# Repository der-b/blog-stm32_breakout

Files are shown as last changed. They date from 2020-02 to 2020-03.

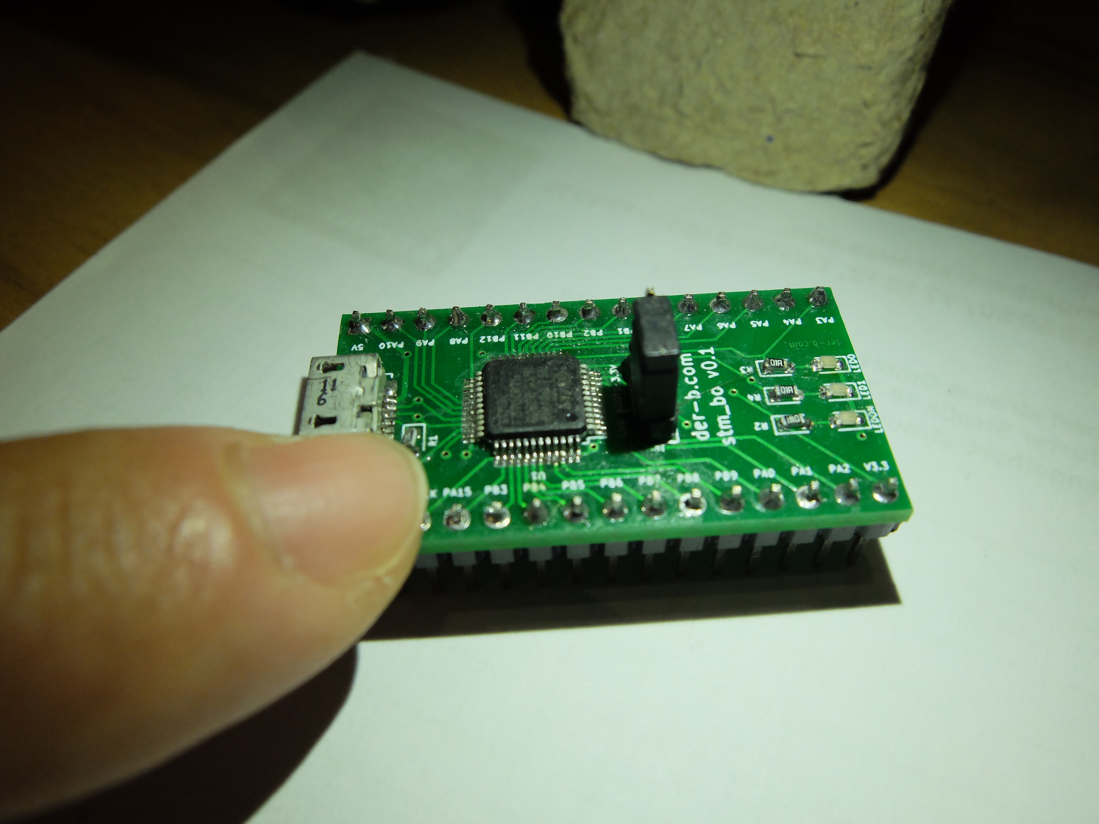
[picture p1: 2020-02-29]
img/DSCF3036.JPG

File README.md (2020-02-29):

# STM32 Breakout

This Project contains all files for my first self designed breakout board with an STM32F070CBT6 microcontroller.

The *schematic* subfolder contains all files related to the board design
The *software* subfolder contains two example firmwares.
In *img* you can find images of the assembled  board.

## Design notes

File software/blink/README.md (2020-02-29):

# Blink

This programm lets the two LEDs on the board blink.

## Compile

``` bash
TARGETS=stm32/f0 make -C libopencm3
make
```

## Download to Board

``` bash
make download
```

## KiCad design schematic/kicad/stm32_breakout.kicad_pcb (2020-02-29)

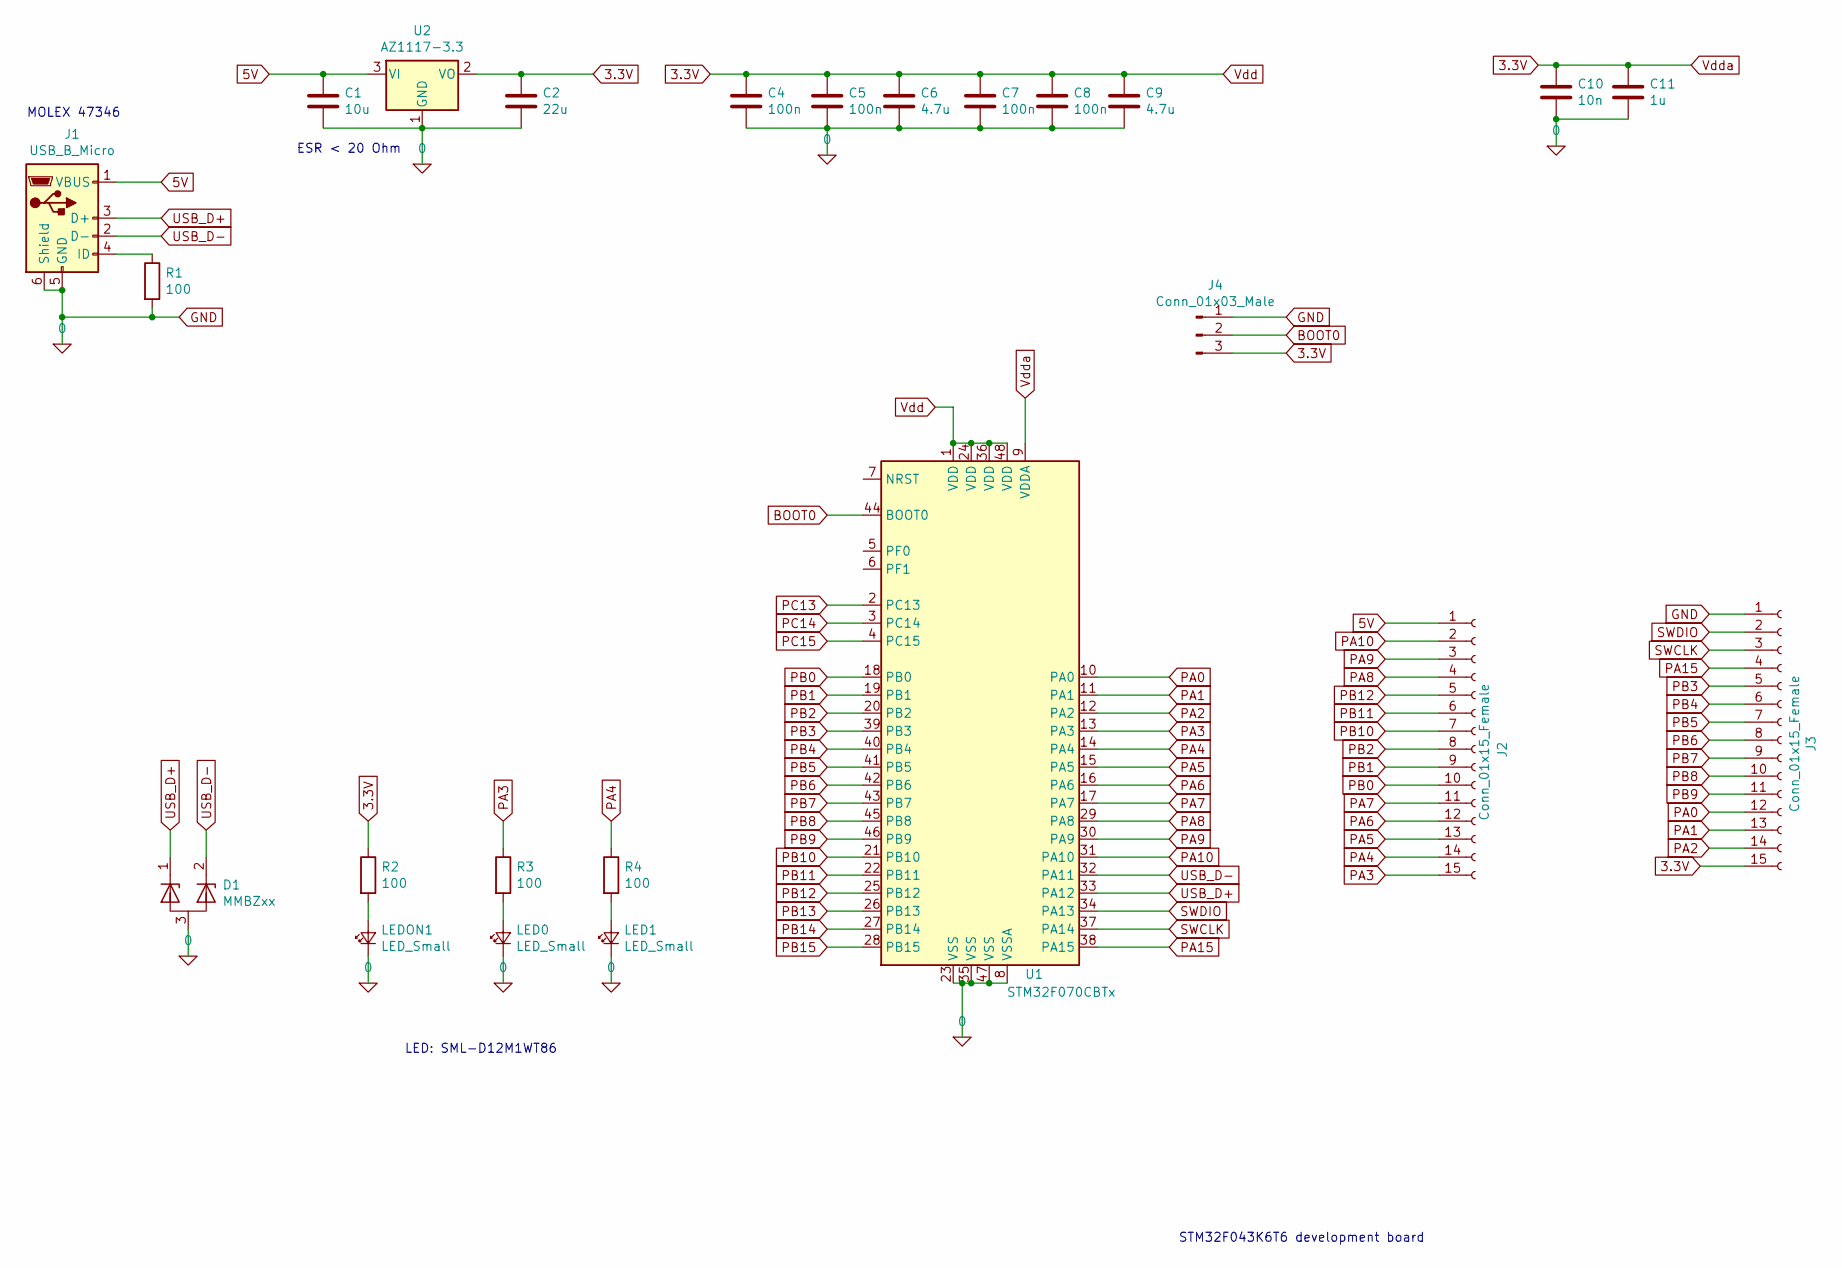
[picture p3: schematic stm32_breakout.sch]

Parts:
C1: 10u; LED_0603_1608Metric
C2: 22u; LED_0603_1608Metric
C4, C5, C7, C8: 100n; LED_0603_1608Metric
C6, C9: 4.7u; LED_0603_1608Metric
C10: 10n; LED_0603_1608Metric
C11: 1u; LED_0603_1608Metric
D1: MMBZxx; SOT-23
J1: USB_B_Micro; USB_Micro-B_Molex_47346-0001
J2, J3: Conn_01x15_Female; PinHeader_1x15_P2.54mm_Vertical
J4: Conn_01x03_Male; PinHeader_1x03_P2.54mm_Vertical
LED0, LED1: LED_Small; LED_0603_1608Metric
LEDON1: LED_Small; LED_0603_1608Metric
R1, R2, R3, R4: 100; LED_0603_1608Metric
U1: STM32F070CBTx; LQFP-48_7x7mm_P0.5mm
U2: AZ1117-3.3; SOT-223

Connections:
3.3V: C2.1, C4.1, C5.1, C6.1, C7.1, C8.1, C9.1, C10.1, C11.1, J3.15, J4.3, R2.1, U1.1 (VDD), U1.9 (VDDA), U1.24 (VDD), U1.36 (VDD), U1.48 (VDD), U2.2 (VO)
5V: C1.1, J1.1 (VBUS), J2.1, U2.3 (VI)
BOOT0: J4.2, U1.44 (BOOT0)
GND: C1.2, C2.2, C4.2, C5.2, C6.2, C7.2, C8.2, C9.2, C10.2, C11.2, D1.3 (A), J1.5 (GND), J1.6 (Shield), J3.1, J4.1, LED0.1 (K), LED1.1 (K), LEDON1.1 (K), R1.2, U1.8 (VSSA), U1.23 (VSS), U1.35 (VSS), U1.47 (VSS), U2.1 (GND); also elsewhere on the board
unnamed: J1.4 (ID), R1.1
unnamed: LED0.2 (A), R3.2
unnamed: LED1.2 (A), R4.2
unnamed 7: LEDON1.2 (A), R2.2; also elsewhere on the board
PA0: J3.12, U1.10 (PA0)
PA1: J3.13, U1.11 (PA1)
PA2: J3.14, U1.12 (PA2)
PA3: J2.15, R3.1, U1.13 (PA3)
PA4: J2.14, R4.1, U1.14 (PA4)
PA5: J2.13, U1.15 (PA5)
PA6: J2.12, U1.16 (PA6)
PA7: J2.11, U1.17 (PA7)
PA8: J2.4, U1.29 (PA8)
PA9: J2.3, U1.30 (PA9)
PA10: J2.2, U1.31 (PA10)
PA15: J3.4, U1.38 (PA15)
PB0: J2.10, U1.18 (PB0)
PB1: J2.9, U1.19 (PB1)
PB2: J2.8, U1.20 (PB2)
PB3: J3.5, U1.39 (PB3)
PB4: J3.6, U1.40 (PB4)
PB5: J3.7, U1.41 (PB5)
PB6: J3.8, U1.42 (PB6)
PB7: J3.9, U1.43 (PB7)
PB8: J3.10, U1.45 (PB8)
PB9: J3.11, U1.46 (PB9)
PB10: J2.7, U1.21 (PB10)
PB11: J2.6, U1.22 (PB11)
PB12: J2.5, U1.25 (PB12)
PB13: U1.26 (PB13)
PB14: U1.27 (PB14)
PB15: U1.28 (PB15)
PC13: U1.2 (PC13)
PC14: U1.3 (PC14)
PC15: U1.4 (PC15)
SWCLK: J3.3, U1.37 (PA14)
SWDIO: J3.2, U1.34 (PA13)
USB_D+: D1.1 (K), J1.3 (D+), U1.33 (PA12)
USB_D-: D1.2 (K), J1.2 (D-), U1.32 (PA11)

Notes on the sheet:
ESR < 20 Ohm
LED: SML-D12M1WT86
MOLEX 47346
STM32F043K6T6 development board

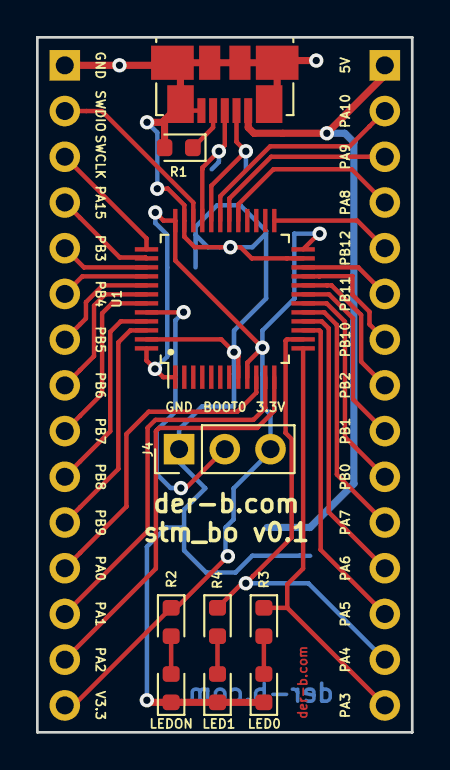
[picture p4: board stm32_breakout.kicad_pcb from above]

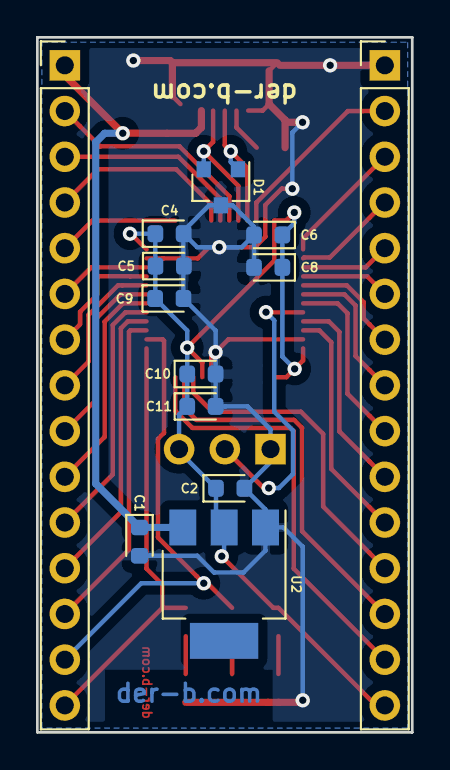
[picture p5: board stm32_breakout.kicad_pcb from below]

Board: 2 copper layers, 20.8 x 38.6 mm, 23 parts (13 on the bottom side), 37 nets.

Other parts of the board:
LEDON: LED_Small; LED_0603_1608Metric

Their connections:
GND: LEDON.1; also elsewhere on the board
unnamed 7: LEDON.2; also elsewhere on the board

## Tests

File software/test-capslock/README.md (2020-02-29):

# Capslock

With this program, the board will register as USB keyboard and listens to the status of caps lock and the numpad status. Depending on the status it will turn on the LEDs.

This is based on [tomu-capslock](https://github.com/der-b/tomu-capslock)

## Compile

``` bash
TARGETS=stm32/f0 make -C libopencm3
make
```

## download to board

``` bash
make download
```

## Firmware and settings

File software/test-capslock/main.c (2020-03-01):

#include <libopencm3/stm32/rcc.h>
#include <libopencm3/stm32/gpio.h>
#include <libopencm3/stm32/exti.h>
#include <libopencm3/stm32/f0/nvic.h>
#include <libopencm3/stm32/timer.h>
#include <libopencm3/usb/usbd.h>
#include <libopencm3/usb/hid.h>

#include <stdbool.h>
#include <stdio.h>
#include <string.h>
#include "HID_Report.h"

#define AHB_FREQUENCY 14000000

#define VENDOR_ID                 0x1209    /* see: http://pid.codes/ */
#define PRODUCT_ID                0x0001    /* test product id: http://pid.codes/1209/0001/ */
#define DEVICE_VER                0x0100    /* Program version */

/* Reference [1]: USB 3.2 Revision 1.0 */
/* Reference [2]: Device Class Definitions for Human Interface Devices (HID) Version 1.11 */
/* Reference [3]: https://eleccelerator.com/tutorial-about-usb-hid-report-descriptors/ */

/* See [1] Table 9-11 */
#define USB_VERSION_2_0 (0x0200)

/* See [1] Table 9-25 "bEndpointAddress" */
#define KEYBOARD_ADDRESS (0x81)

/* Buffer to be used for control requests. */
uint8_t usbd_control_buffer[128];
usbd_device *g_usbd_dev = 0;

/*
 * Example from [2] Section E.6
 */
static const uint8_t hid_report[] = {
USAGE_PAGE (GENERIC_DESKTOP_CONTROLS),
USAGE (KEYBOARD),
COLLECTION (APPLICATION),
	USAGE_PAGE (KEYBOARD_KEYPAD),
	USAGE_MINIMUM (224),
	USAGE_MAXIMUM (231),
	LOGICAL_MINIMUM (0),
	LOGICAL_MAXIMUM (1),
	REPORT_SIZE (1),
	REPORT_COUNT (8),
	INPUT (DATA | VARIABLE | ABSOLUTE),

	REPORT_COUNT (1),
	REPORT_SIZE (8),
	INPUT (CONSTANT),

	REPORT_COUNT (6),
	REPORT_SIZE (8),
	LOGICAL_MINIMUM (0),
	LOGICAL_MAXIMUM (101),
	USAGE_PAGE (KEYBOARD_KEYPAD),
	USAGE_MINIMUM (0),
	USAGE_MAXIMUM (101),
	INPUT (DATA | ARRAY),

	REPORT_COUNT (5),
	REPORT_SIZE (1),
	USAGE_PAGE (LEDS),
	USAGE_MINIMUM (1),
	USAGE_MAXIMUM (7),
	OUTPUT (DATA | VARIABLE | ABSOLUTE),

	REPORT_COUNT (1),
	REPORT_SIZE (3),
	OUTPUT (CONSTANT),

END_COLLECTION, // END_COLLECTION
};


/*
 * See [2] Section 6.2.1
 */
struct tomu_hid_report {
	struct usb_hid_descriptor hid_d;
	uint8_t bDescriptorType;
	uint16_t wDescriptorLenght;
} __attribute__((packed));

/*
 * Device descriptor
 * See [1] Table 9-11
 */
static const struct usb_device_descriptor dev_desc = {
	.bLength = USB_DT_DEVICE_SIZE,
	.bDescriptorType = USB_DT_DEVICE,
	.bcdUSB = USB_VERSION_2_0,
	.bDeviceClass = 0, // we have to set it to 0 to be compliant with [2] Section 5.1 
	.bDeviceSubClass = 0, // compliant to [1] Table 9-11
	.bDeviceProtocol = 0,
	.bMaxPacketSize0 = 8,
	.idVendor = VENDOR_ID,
	.idProduct = PRODUCT_ID,
	.bcdDevice = DEVICE_VER,
	.iManufacturer = 1,
	.iProduct = 2,
	.iSerialNumber = 3,
	.bNumConfigurations = 1,
};


/*
 * endpoint descriptor
 * See [1] Table 9-25
 */
const struct usb_endpoint_descriptor hid_endpoint = {
	.bLength = USB_DT_ENDPOINT_SIZE,
	.bDescriptorType = USB_DT_ENDPOINT,
	.bEndpointAddress = KEYBOARD_ADDRESS, // address 1, direction IN
	.bmAttributes = USB_ENDPOINT_ATTR_INTERRUPT, // interrupt, periodic poll 
#warning "You should check this"
	.wMaxPacketSize = 8,
	.bInterval = 0x20, // poll every 2 ms
};


/*
 *
 */
static const struct tomu_hid_report hid_desc ={
	.hid_d.bLength = sizeof(hid_desc),
	.hid_d.bDescriptorType = USB_DT_HID, // see [2] Section 7.1
	.hid_d.bcdHID = 0x0100, // hid revision (see [2] Section 6.2.1 and for an example Section E.4 or E.8)
	.hid_d.bCountryCode = 0,
	.hid_d.bNumDescriptors = 1,
	.bDescriptorType = USB_DT_REPORT, // see [2] Section 7.1
	.wDescriptorLenght = sizeof(hid_report),
};


/*
 * interface descriptor
 * See [1] Table 9-24
 */
const struct usb_interface_descriptor hid_interface = {
	.bLength = USB_DT_INTERFACE_SIZE,
	.bDescriptorType = USB_DT_INTERFACE,
	.bInterfaceNumber = 0,
	.bAlternateSetting = 0,
	.bNumEndpoints = 1,
	.bInterfaceClass = USB_CLASS_HID, // USB_CLASS_HID=3 (see [2] section 4.1)
	.bInterfaceSubClass = 0, // no boot interface (see [2] section 4.2)
	.bInterfaceProtocol = 1, // it is a keyboard (see [2] section 4.3)
	.iInterface = 0,

	.endpoint = &hid_endpoint,
	.extra = &hid_desc,
	.extralen = sizeof(hid_desc),
};

const struct usb_interface interfaces[] = {{
	.num_altsetting = 1,
	.altsetting = &hid_interface,
}};

/*
 * USB Configuration Descriptor
 * See [1] Table 9-22
 */
const struct usb_config_descriptor config_desc = {
	.bLength = USB_DT_CONFIGURATION_SIZE,
	.bDescriptorType = USB_DT_CONFIGURATION,
#warning "check this"
	.wTotalLength = sizeof(hid_interface) + sizeof(hid_desc) + sizeof(hid_report) + sizeof(hid_endpoint), 
	.bNumInterfaces = 1,
	.bConfigurationValue = 1,
	.iConfiguration = 0,
	.bmAttributes = USB_CONFIG_ATTR_DEFAULT | USB_CONFIG_ATTR_SELF_POWERED, // self powered
	.bMaxPower = 50, // we will draw 100 mA at max
	.interface = interfaces,
};

static const char *usb_strings[] = {
	"STM32 Breakout Board Capslock Indicator",
	"HID keyboard Demo",
	"http://der-b.com",
};



static enum usbd_request_return_codes hid_control_request(usbd_device *dev, struct usb_setup_data *req, uint8_t **buf, uint16_t *len,
			void (**complete)(usbd_device *, struct usb_setup_data *))
{
	(void)complete;
	(void)dev;

	if((req->bmRequestType != KEYBOARD_ADDRESS) ||
	   (req->bRequest != USB_REQ_GET_DESCRIPTOR) ||
	   (req->wValue != 0x2200))
		return 0;

	/* Handle the HID report descriptor. */
	*buf = (uint8_t *)hid_report;
	*len = sizeof(hid_report);

	return 1;
}

void usb_isr(void)
{
}


static enum usbd_request_return_codes usb_rx(usbd_device *dev, struct usb_setup_data *req, uint8_t **buf, uint16_t *len,
			void (**complete)(usbd_device *, struct usb_setup_data *))
{
	(void)dev;
	(void)buf;
	(void)len;
	(void)complete;

	if (   USB_REQ_SET_CONFIGURATION != req->bRequest
	    || 1 != req->wLength
	    || 0 != req->wIndex)
		return 0;

	if (0x1 << 1 & (*buf)[0]) {
		gpio_set(GPIOA, GPIO4);
	} else {
		gpio_clear(GPIOA, GPIO4);
	}
	if (0x1 << 0 & (*buf)[0]) {
		gpio_set(GPIOA, GPIO3);
	} else {
		gpio_clear(GPIOA, GPIO3);
	}
	return 1;
}

static void hid_set_config(usbd_device *dev, uint16_t wValue)
{
	(void)wValue;
	(void)dev;

	usbd_ep_setup(dev, KEYBOARD_ADDRESS, USB_ENDPOINT_ATTR_INTERRUPT, 8, NULL);

	usbd_register_control_callback(
				dev,
				USB_REQ_TYPE_STANDARD | USB_REQ_TYPE_INTERFACE,
				USB_REQ_TYPE_TYPE | USB_REQ_TYPE_RECIPIENT,
				hid_control_request);

	usbd_register_control_callback(
				dev,
				USB_REQ_TYPE_OUT       | USB_REQ_TYPE_CLASS | USB_REQ_TYPE_INTERFACE,
				USB_REQ_TYPE_DIRECTION | USB_REQ_TYPE_TYPE  | USB_REQ_TYPE_RECIPIENT,
				usb_rx);
}

void hard_fault_handler(void)
{
    while(1);
}

int main(void)
{
    rcc_clock_setup_in_hsi_out_48mhz();

    rcc_periph_clock_enable(RCC_GPIOA);
    rcc_periph_clock_enable(RCC_GPIOB);
    
    gpio_mode_setup(GPIOA, GPIO_MODE_OUTPUT, GPIO_PUPD_NONE, GPIO4);
    gpio_mode_setup(GPIOA, GPIO_MODE_OUTPUT, GPIO_PUPD_NONE, GPIO3);

    rcc_set_usbclk_source(RCC_PLL);
    rcc_periph_clock_enable(RCC_USB);
    rcc_wait_for_osc_ready(rcc_usb_clock_source());

    /* USB initialisation */
    g_usbd_dev = usbd_init(&st_usbfs_v2_usb_driver, &dev_desc, &config_desc, usb_strings, 3, usbd_control_buffer, sizeof(usbd_control_buffer));
    usbd_register_set_config_callback(g_usbd_dev, hid_set_config);

    while(1) {
	    usbd_poll(g_usbd_dev);
    }
}

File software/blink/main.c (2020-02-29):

#include <libopencm3/stm32/rcc.h>
#include <libopencm3/stm32/gpio.h>

#define LED1_PORT GPIOA
#define LED1_PIN  GPIO4

#define LED0_PORT GPIOA
#define LED0_PIN  GPIO3

int main(void)
{
        // enable the GPIO port A
	rcc_periph_clock_enable(RCC_GPIOA);

        // set LED pins as floating output with pull up resistor
	gpio_mode_setup(LED0_PORT, GPIO_MODE_OUTPUT, GPIO_PUPD_PULLUP, LED0_PIN);
	gpio_mode_setup(LED1_PORT, GPIO_MODE_OUTPUT, GPIO_PUPD_PULLUP, LED1_PIN);

        // turn on LED0
	gpio_set(LED0_PORT, LED0_PIN);

        // turn off LED1
	gpio_clear(LED1_PORT, LED1_PIN);

	while(1) {
                // busy wait some time
		for (int i = 0; i < 500000; ++i) {
			__asm__("nop");
		}

                // change the state of both LEDs
		gpio_toggle(LED1_PORT, LED0_PIN | LED1_PIN);
	}

	return 0;
}

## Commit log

2020-02-29 Added all files.
    [stm32_breakout.kicad_pcb, stm32_breakout.sch]
2020-03-01 Changed the USB Product ID to the test ID of the pid.codes project: http://pid.codes/1209/0001/
